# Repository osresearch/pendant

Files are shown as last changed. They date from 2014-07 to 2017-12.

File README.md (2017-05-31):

Bootloader
===

The ATtiny85 needs to be flashed with a bootloader before it can
be programmed with the Arduino IDE.  This requires extra hardware,
such as a teensy or arduino configured as an ISP.

The bootloader is then flashed via an SOIC socket.  It is possible to
via a chip clip, but this seems to be somewhat flakey due to the
charlieplexing matrix.

Using the arduino IDE, select "`File`-`Examples`-`11. Arduino ISP`"
and set the "`Tools`-`Board`" for whatever type of arduino or teensy you 
are using.  For a teensy the minimum pinout is:

	Teensy	SOIC	Use
	Vcc	8
	GND	4
	1	7	SCK
	2	5	MOSI
	3	6	MISO
	10	1	Reset

Clone the bootloader tree:

    git clone https://github.com/osresearch/gemma-bootloader

You might have to edit the `gemma-bootloader/Makefile` to have the
right path to your Arduino build environment and `avrdude` tool.  You will
likely have to edit it to set the serial device that your Teensy or
Arduino shows up as.

Connect the ArduinoISP to the ATtiny85 and flash the bootloader:

    make -C gemma-bootloader flash_lv

This should result in an ok message.  if it doesn't, check the connections
and try again.  If it is succesful you won't be able to reflash it,
since the reset pin is disabled.

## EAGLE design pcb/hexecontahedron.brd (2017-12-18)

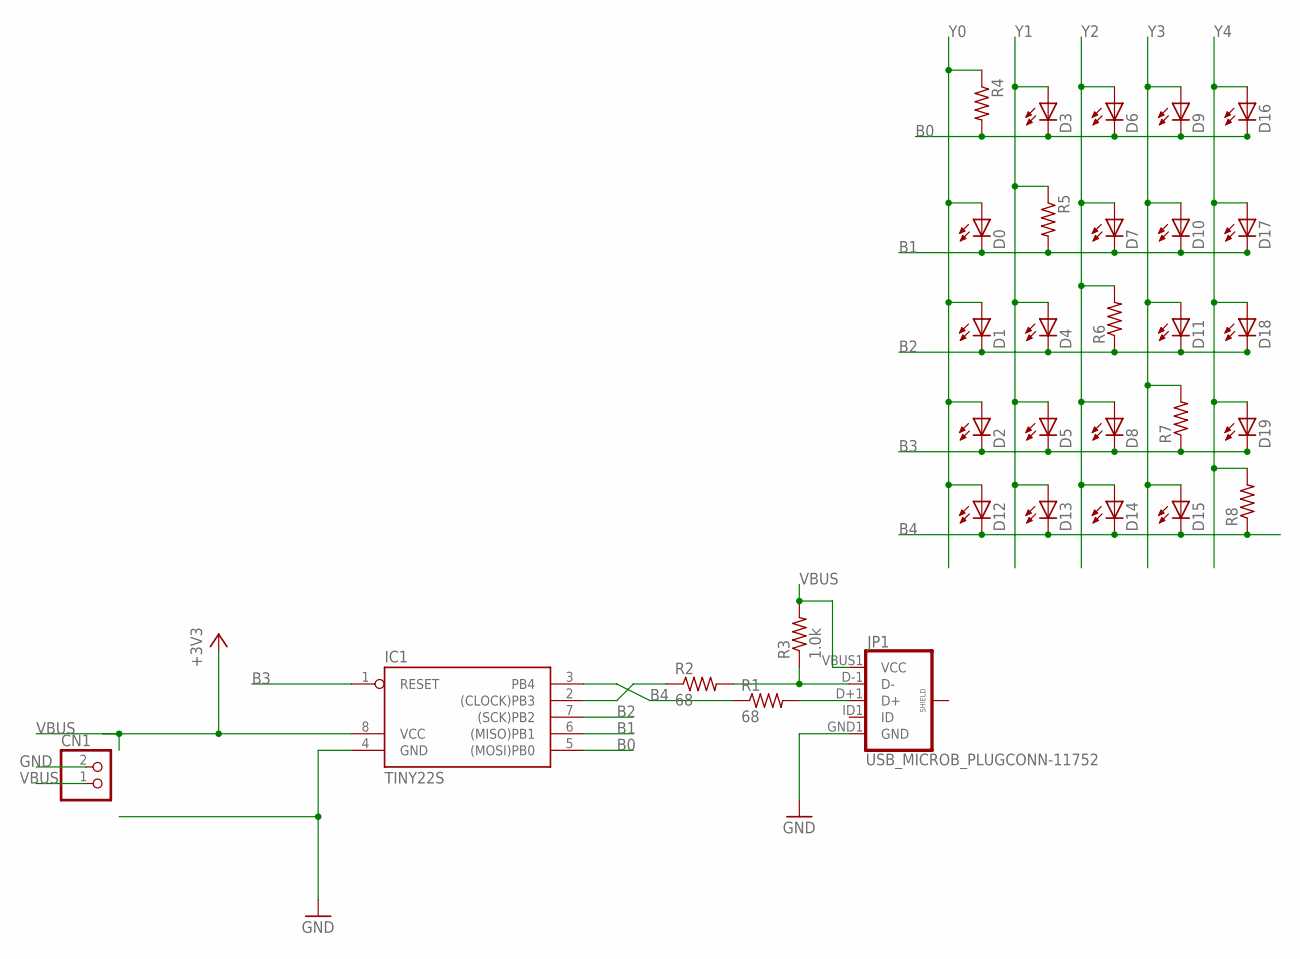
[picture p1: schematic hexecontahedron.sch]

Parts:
CN1: JST_2PIN-THM-RA; JST-PH-2-THM-RA
D0, D1, D2, D3, D4, D5, D6, D7, D8, D9, D10, D11, D12, D13, D14, D15, D16, D17, D18, D19: LEDCHIPLED_0805; CHIPLED_0805
IC1: TINY22S; SOIC8
JP1: USB_MICROB_PLUGCONN-11752; USB-B-MICRO-SMD_V03
R1, R2: 68; R0603
R3: 1.0k; R0603
R4, R5, R6, R7, R8: R-US_R0603; R0603

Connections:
B0: D3.C, D6.C, D9.C, D16.C, IC1.5 ((MOSI)PB0), R4.2
B1: D0.C, D7.C, D10.C, D17.C, IC1.6 ((MISO)PB1), R5.2
B2: D1.C, D4.C, D11.C, D18.C, IC1.7 ((SCK)PB2), R6.1
B3: D2.C, D5.C, D8.C, D19.C, IC1.1 (RESET), R7.1
B4: D12.C, D13.C, D14.C, D15.C, IC1.3 (PB4), R1.1, R8.1
GND: CN1.2 (1), IC1.4 (GND), JP1.GND1 (GND)
unnamed: JP1.D+1 (D+), R1.2
unnamed: JP1.D-1 (D-), R2.2, R3.1
unnamed: IC1.2 ((CLOCK)PB3), R2.1
VBUS: CN1.1 (2), IC1.8 (VCC), JP1.VBUS1 (VCC), R3.2
Y0: D0.A, D1.A, D2.A, D12.A, R4.1
Y1: D3.A, D4.A, D5.A, D13.A, R5.1
Y2: D6.A, D7.A, D8.A, D14.A, R6.2
Y3: D9.A, D10.A, D11.A, D15.A, R7.2
Y4: D16.A, D17.A, D18.A, D19.A, R8.2

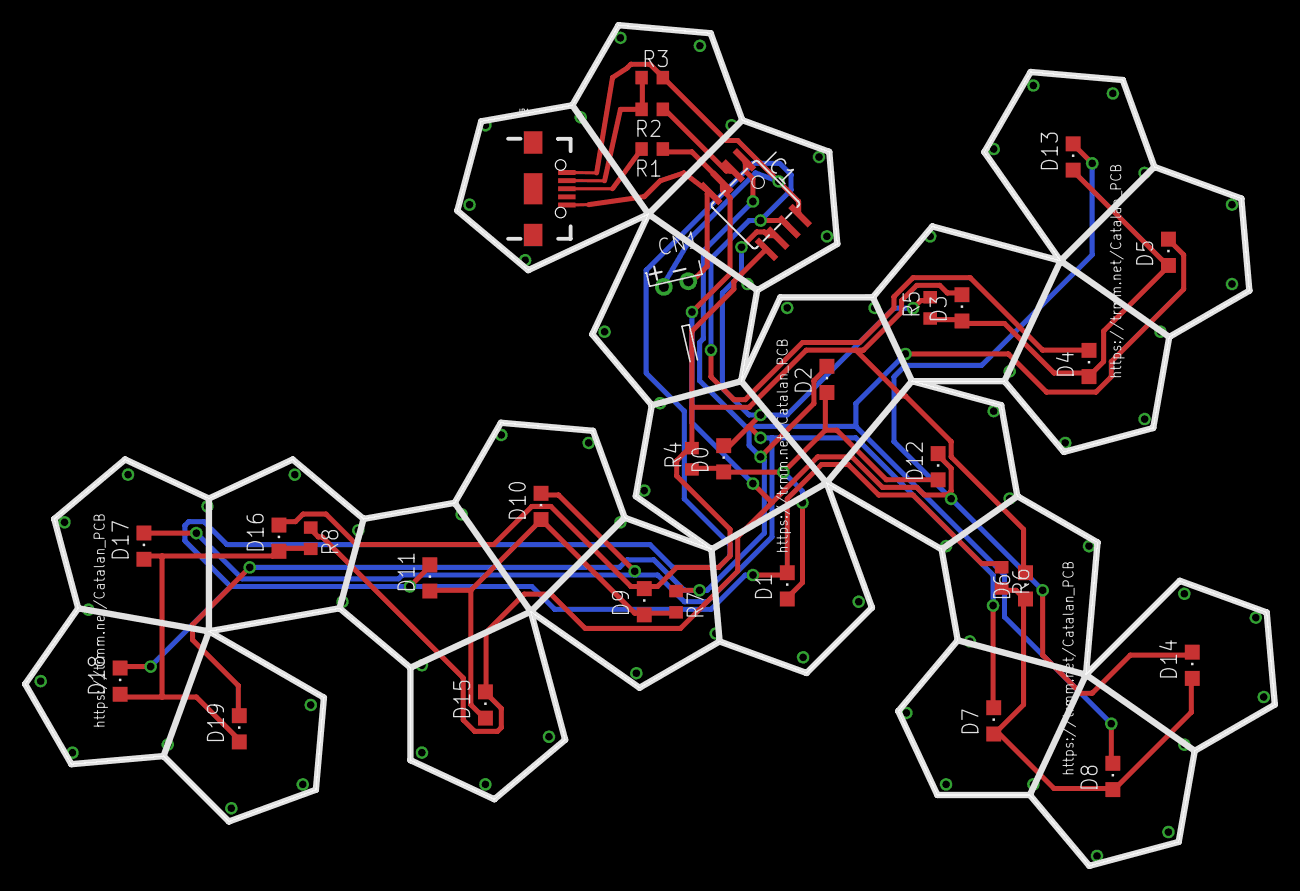
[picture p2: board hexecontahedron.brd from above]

Board: 2 copper layers, 99.9 x 67.2 mm, 31 parts (0 on the bottom side), 15 nets.

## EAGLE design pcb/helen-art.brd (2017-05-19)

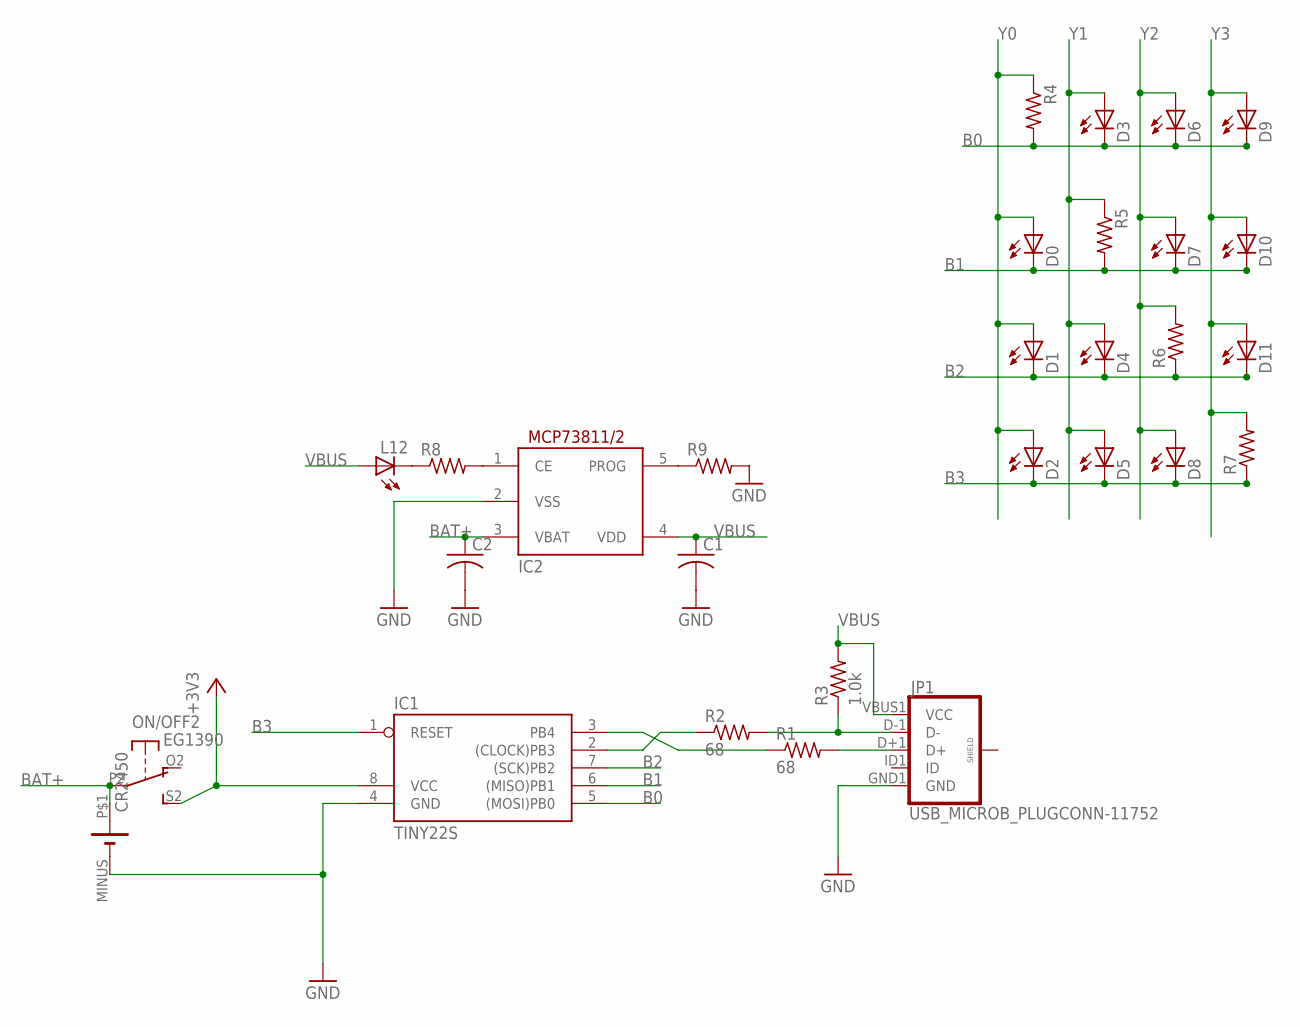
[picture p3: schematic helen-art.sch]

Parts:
C1, C2: C-USC0603; C0603
D0, D1, D2, D3, D4, D5, D6, D7, D8, D9, D10, D11: LEDCHIPLED_0805; CHIPLED_0805
IC1: TINY22S; SOIC8
IC2: MCP73811/2; SOT23-5L
JP1: USB_MICROB_PLUGCONN-11752; USB-B-MICRO-SMD_V03
L12: LEDCHIPLED_0805; CHIPLED_0805
ON/OFF: EG1390
R1, R2: 68; R0603
R3: 1.0k; R0603
R4, R5, R6, R7, R8, R9: R-US_R0603; R0603
U$3: CR2450; CR2450_KEYSTONE

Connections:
+3V3: IC1.8 (VCC), ON/OFF.S2 (S)
B0: D3.C, D6.C, D9.C, IC1.5 ((MOSI)PB0), R4.2
B1: D0.C, D7.C, D10.C, IC1.6 ((MISO)PB1), R5.2
B2: D1.C, D4.C, D11.C, IC1.7 ((SCK)PB2), R6.1
B3: D2.C, D5.C, D8.C, IC1.1 (RESET), R7.1
BAT+: C2.1, IC2.3 (VBAT), ON/OFF.P2, U$3.P$1 (+)
GND: C1.2, C2.2, IC1.4 (GND), IC2.2 (VSS), JP1.GND1 (GND), R9.2, U$3.MINUS (-)
unnamed: JP1.D+1 (D+), R1.2
unnamed: JP1.D-1 (D-), R2.2, R3.1
unnamed: IC1.3 (PB4), R1.1
unnamed: IC1.2 ((CLOCK)PB3), R2.1
unnamed: IC2.5 (PROG), R9.1
unnamed: IC2.1 (CE), R8.2
unnamed: L12.C, R8.1
VBUS: C1.1, IC2.4 (VDD), JP1.VBUS1 (VCC), L12.A, R3.2
Y0: D0.A, D1.A, D2.A, R4.1
Y1: D3.A, D4.A, D5.A, R5.1
Y2: D6.A, D7.A, D8.A, R6.2
Y3: D9.A, D10.A, D11.A, R7.2

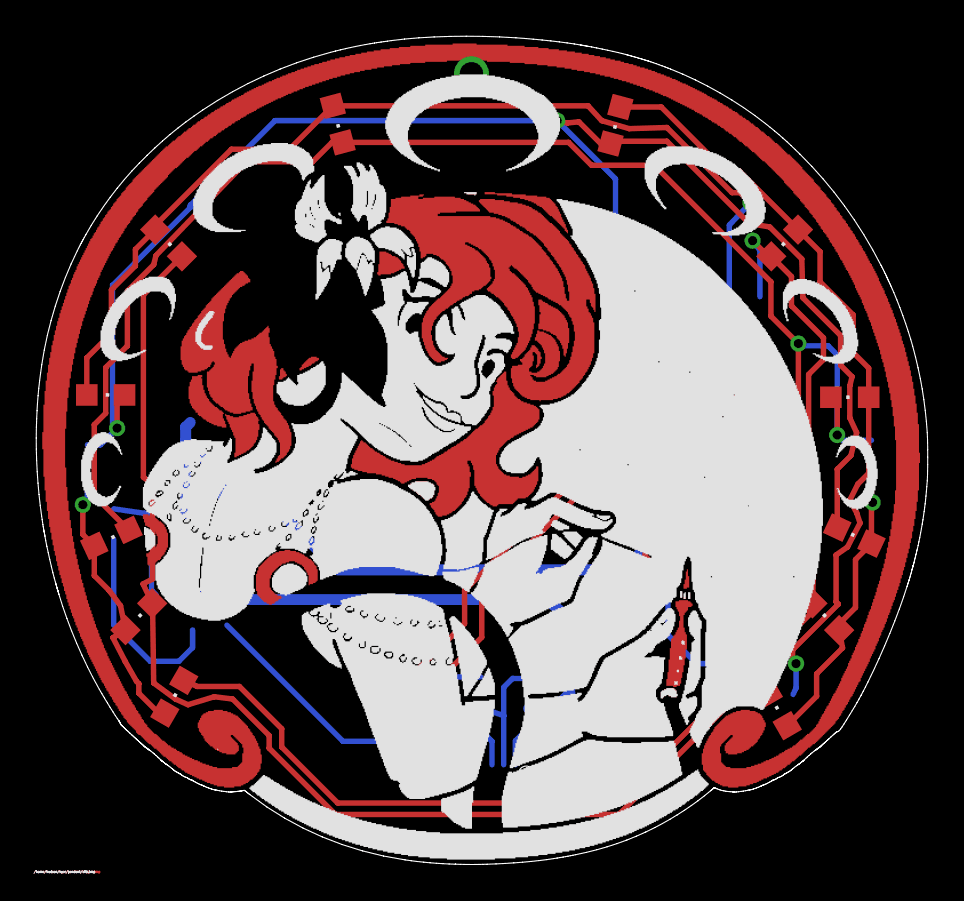
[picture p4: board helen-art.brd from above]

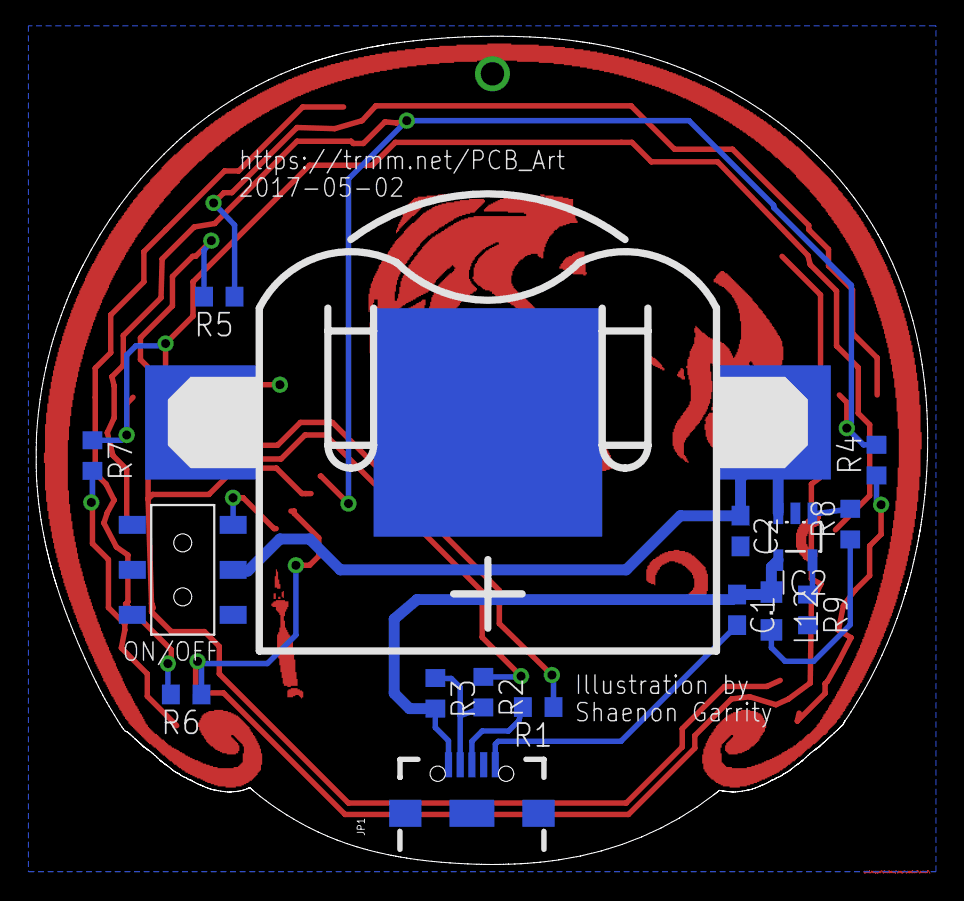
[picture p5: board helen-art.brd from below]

Board: 2 copper layers, 49.5 x 46.0 mm, 29 parts (16 on the bottom side), 19 nets.

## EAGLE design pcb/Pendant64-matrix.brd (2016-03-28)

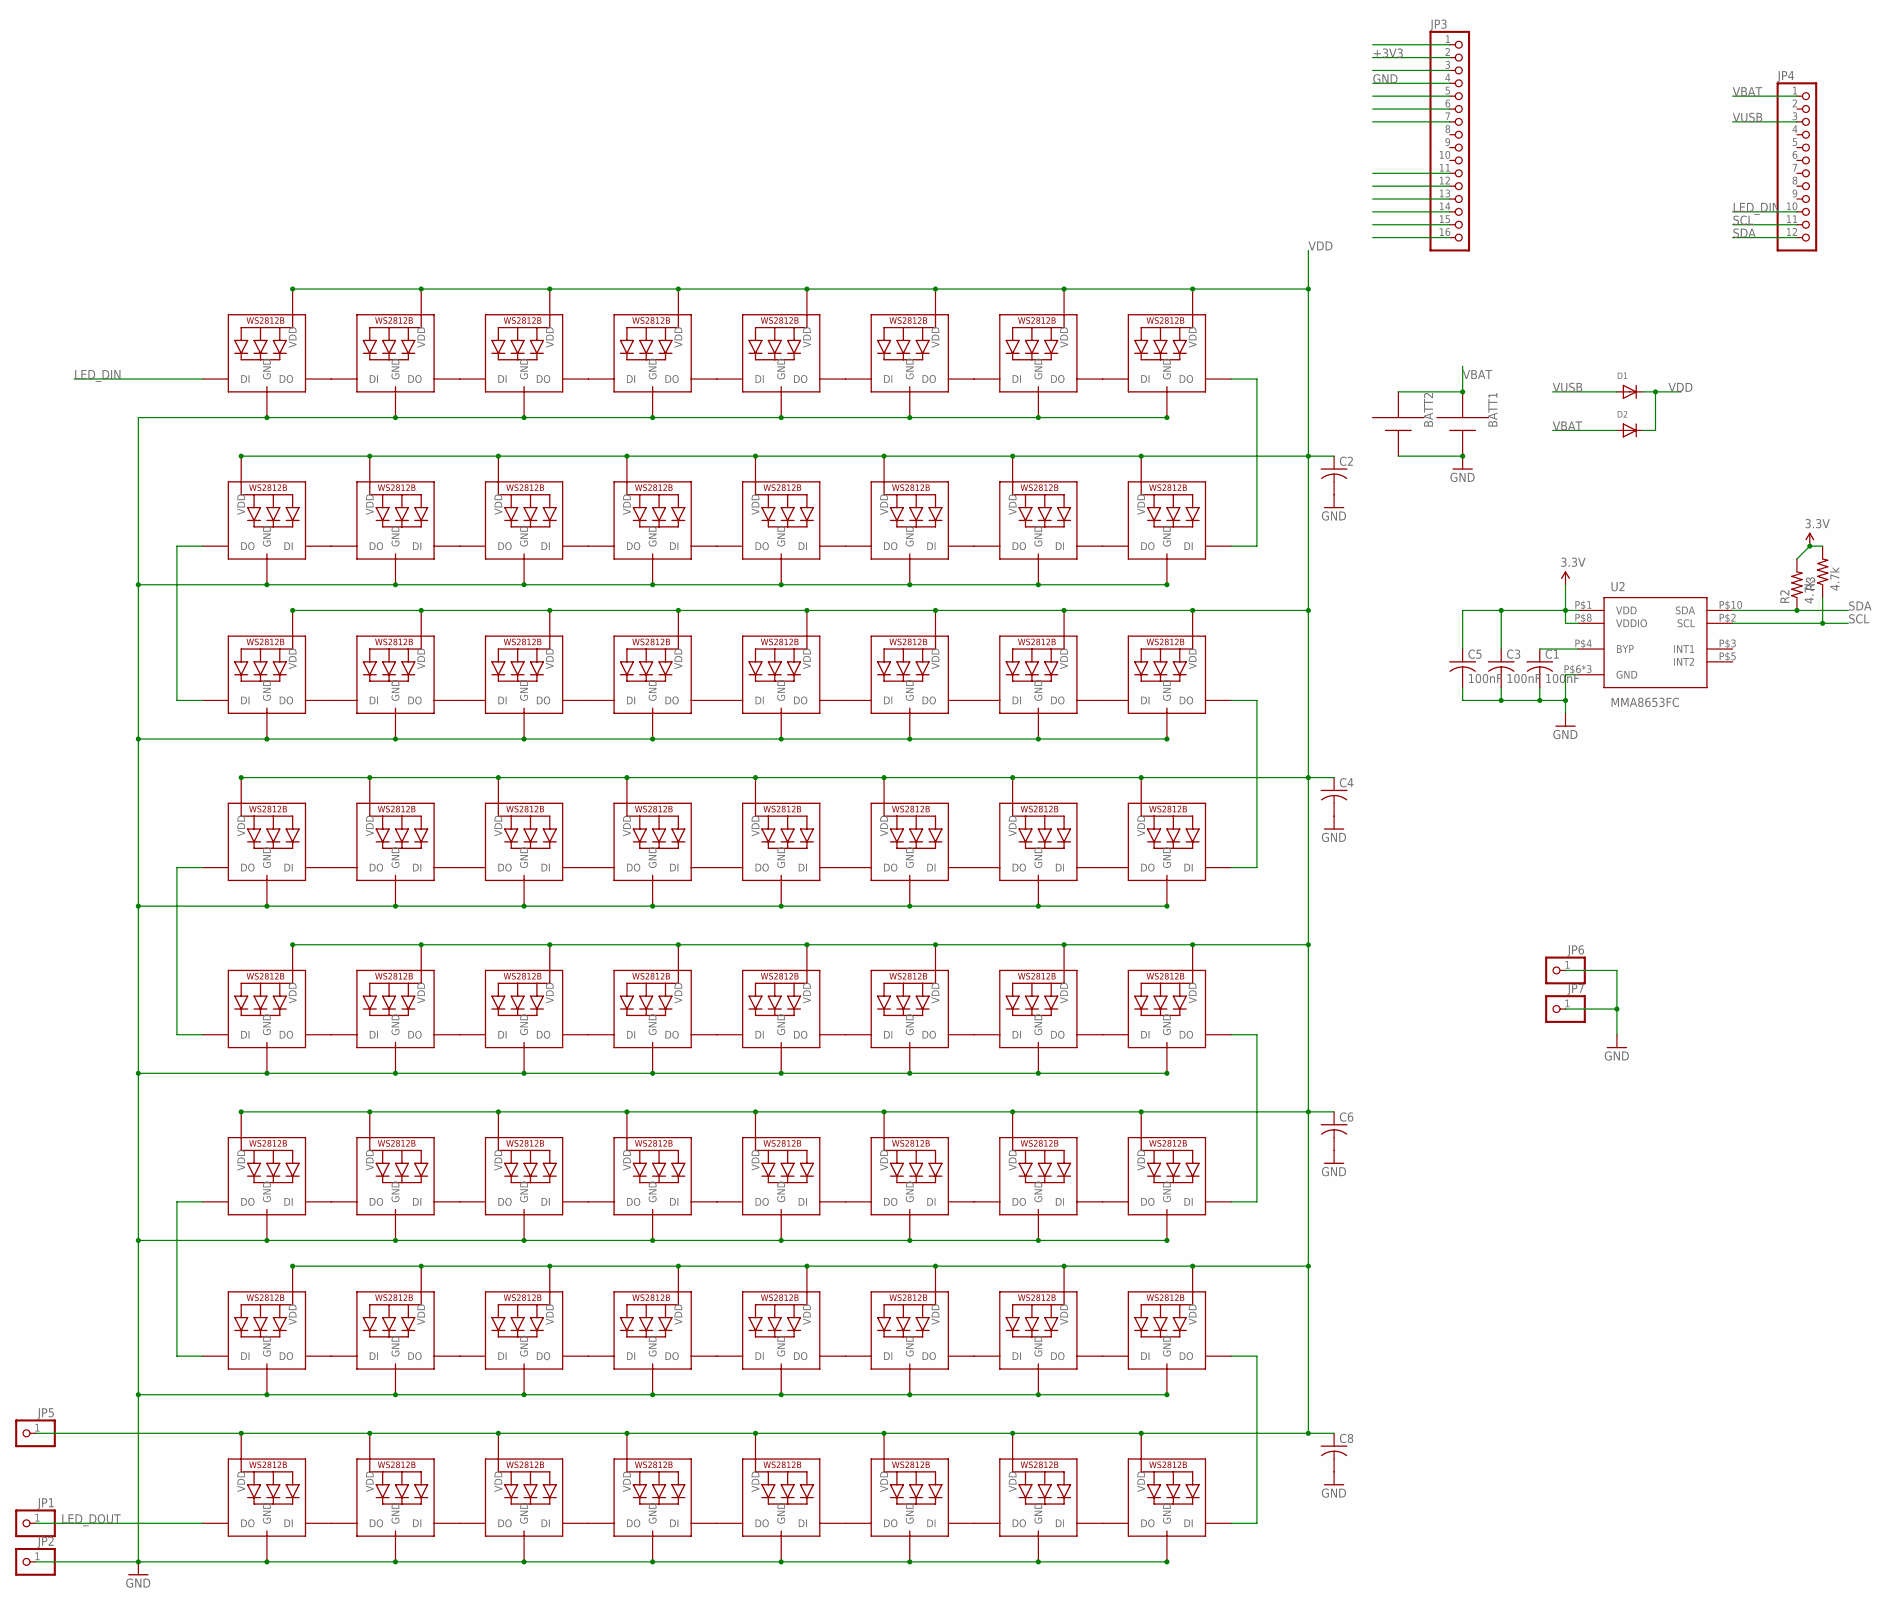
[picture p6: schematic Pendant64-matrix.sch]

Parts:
BATT1, BATT2: AAA; 12BH412
C1, C3, C5: 100nF; C0402
C2, C4, C6, C8: C-USC0402K; C0402K
D1, D2: DIODESOD-123; SOD-123
JP1, JP2, JP5, JP6, JP7: PINHD-1X1; 1X01
JP3: PINHD-1X161X16_SMT; 1X16_SMT
JP4: PINHD-1X121X12_SMT; 1X12_SMT
LED1, LED2, LED3, LED4, LED5, LED6, LED7, LED8, LED9, LED10, LED11, LED12, LED13, LED14, LED15, LED16, LED17, LED18, LED19, LED20, LED21, LED22, LED23, LED24, LED25, LED26, LED27, LED28, LED29, LED30, LED31, LED32, LED33, LED34, LED35, LED36, LED37, LED38, LED39, LED40, LED41, LED42, LED43, LED44, LED45, LED46, LED47, LED48, LED49, LED50, LED51, LED52, LED53, LED54, LED55, LED56, LED57, LED58, LED59, LED60, LED61, LED62, LED63, LED64: WS2812B3535; LED3535
R2, R3: 4.7k; R0402
U2: MMA8653FC; VFDFN-10

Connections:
+3V3: C3.1, C5.1, JP3.2, R2.2, R3.2, U2.P$1 (VDD), U2.P$8 (VDDIO)
GND: BATT1.+, BATT2.+, C1.2, C2.2, C3.2, C4.2, C5.2, C6.2, C8.2, JP2.1, JP3.4, JP6.1, JP7.1, LED1.4 (GND), LED2.4 (GND), LED3.4 (GND), LED4.4 (GND), LED5.4 (GND), LED6.4 (GND), LED7.4 (GND), LED8.4 (GND), LED9.4 (GND), LED10.4 (GND), LED11.4 (GND), LED12.4 (GND), LED13.4 (GND), LED14.4 (GND), LED15.4 (GND), LED16.4 (GND), LED17.4 (GND), LED18.4 (GND), LED19.4 (GND), LED20.4 (GND), LED21.4 (GND), LED22.4 (GND), LED23.4 (GND), LED24.4 (GND), LED25.4 (GND), LED26.4 (GND), LED27.4 (GND), LED28.4 (GND), LED29.4 (GND), LED30.4 (GND), LED31.4 (GND), LED32.4 (GND), LED33.4 (GND), LED34.4 (GND), LED35.4 (GND), LED36.4 (GND), LED37.4 (GND), LED38.4 (GND), LED39.4 (GND), LED40.4 (GND), LED41.4 (GND), LED42.4 (GND), LED43.4 (GND), LED44.4 (GND), LED45.4 (GND), LED46.4 (GND), LED47.4 (GND), LED48.4 (GND), LED49.4 (GND), LED50.4 (GND), LED51.4 (GND), LED52.4 (GND), LED53.4 (GND), LED54.4 (GND), LED55.4 (GND), LED56.4 (GND), LED57.4 (GND), LED58.4 (GND), LED59.4 (GND), LED60.4 (GND), LED61.4 (GND), LED62.4 (GND), LED63.4 (GND), LED64.4 (GND), U2.P$6 (GND), U2.P$7 (GND), U2.P$9 (GND)
LED_DIN: JP4.10, LED1.1 (DI)
LED_DOUT: JP1.1, LED64.3 (DO)
unnamed: LED1.3 (DO), LED2.1 (DI)
unnamed: LED2.3 (DO), LED3.1 (DI)
unnamed: LED3.3 (DO), LED4.1 (DI)
unnamed: LED4.3 (DO), LED5.1 (DI)
unnamed: LED5.3 (DO), LED6.1 (DI)
unnamed: LED6.3 (DO), LED7.1 (DI)
unnamed: LED7.3 (DO), LED8.1 (DI)
unnamed: LED9.3 (DO), LED10.1 (DI)
unnamed: LED10.3 (DO), LED11.1 (DI)
unnamed: LED11.3 (DO), LED12.1 (DI)
unnamed: LED12.3 (DO), LED13.1 (DI)
unnamed: LED13.3 (DO), LED14.1 (DI)
unnamed: LED14.3 (DO), LED15.1 (DI)
unnamed: LED15.3 (DO), LED16.1 (DI)
unnamed: LED17.3 (DO), LED18.1 (DI)
unnamed: LED18.3 (DO), LED19.1 (DI)
unnamed: LED19.3 (DO), LED20.1 (DI)
unnamed: LED20.3 (DO), LED21.1 (DI)
unnamed: LED21.3 (DO), LED22.1 (DI)
unnamed: LED22.3 (DO), LED23.1 (DI)
unnamed: LED23.3 (DO), LED24.1 (DI)
unnamed: LED25.3 (DO), LED26.1 (DI)
unnamed: LED26.3 (DO), LED27.1 (DI)
unnamed: LED27.3 (DO), LED28.1 (DI)
unnamed: LED28.3 (DO), LED29.1 (DI)
unnamed: LED29.3 (DO), LED30.1 (DI)
unnamed: LED30.3 (DO), LED31.1 (DI)
unnamed: LED31.3 (DO), LED32.1 (DI)
unnamed: LED33.3 (DO), LED34.1 (DI)
unnamed: LED34.3 (DO), LED35.1 (DI)
unnamed: LED8.3 (DO), LED9.1 (DI)
unnamed: LED16.3 (DO), LED17.1 (DI)
unnamed: LED24.3 (DO), LED25.1 (DI)
unnamed: LED32.3 (DO), LED33.1 (DI)
unnamed: LED35.3 (DO), LED36.1 (DI)
unnamed: LED36.3 (DO), LED37.1 (DI)
unnamed: LED37.3 (DO), LED38.1 (DI)
unnamed: LED38.3 (DO), LED39.1 (DI)
unnamed: LED39.3 (DO), LED40.1 (DI)
unnamed: LED41.3 (DO), LED42.1 (DI)
unnamed: LED42.3 (DO), LED43.1 (DI)
unnamed: LED43.3 (DO), LED44.1 (DI)
unnamed: LED44.3 (DO), LED45.1 (DI)
unnamed: LED45.3 (DO), LED46.1 (DI)
unnamed: LED46.3 (DO), LED47.1 (DI)
unnamed: LED47.3 (DO), LED48.1 (DI)
unnamed: LED49.3 (DO), LED50.1 (DI)
unnamed: LED50.3 (DO), LED51.1 (DI)
unnamed: LED51.3 (DO), LED52.1 (DI)
unnamed: LED52.3 (DO), LED53.1 (DI)
unnamed: LED53.3 (DO), LED54.1 (DI)
unnamed: LED54.3 (DO), LED55.1 (DI)
unnamed: LED55.3 (DO), LED56.1 (DI)
unnamed: LED57.3 (DO), LED58.1 (DI)
unnamed: LED58.3 (DO), LED59.1 (DI)
unnamed: LED59.3 (DO), LED60.1 (DI)
unnamed: LED60.3 (DO), LED61.1 (DI)
unnamed: LED61.3 (DO), LED62.1 (DI)
unnamed: LED62.3 (DO), LED63.1 (DI)
unnamed: LED63.3 (DO), LED64.1 (DI)
unnamed: C1.1, U2.P$4 (BYP)
unnamed: LED40.3 (DO), LED41.1 (DI)
unnamed: LED48.3 (DO), LED49.1 (DI)
unnamed: LED56.3 (DO), LED57.1 (DI)
SCL: JP4.11, R3.1, U2.P$2 (SCL)
SDA: JP4.12, R2.1, U2.P$10 (SDA)
VBAT: BATT1.-, BATT2.-, D2.A, JP4.1
VDD: C2.1, C4.1, C6.1, C8.1, D1.C, D2.C, JP5.1, LED1.2 (VDD), LED2.2 (VDD), LED3.2 (VDD), LED4.2 (VDD), LED5.2 (VDD), LED6.2 (VDD), LED7.2 (VDD), LED8.2 (VDD), LED9.2 (VDD), LED10.2 (VDD), LED11.2 (VDD), LED12.2 (VDD), LED13.2 (VDD), LED14.2 (VDD), LED15.2 (VDD), LED16.2 (VDD), LED17.2 (VDD), LED18.2 (VDD), LED19.2 (VDD), LED20.2 (VDD), LED21.2 (VDD), LED22.2 (VDD), LED23.2 (VDD), LED24.2 (VDD), LED25.2 (VDD), LED26.2 (VDD), LED27.2 (VDD), LED28.2 (VDD), LED29.2 (VDD), LED30.2 (VDD), LED31.2 (VDD), LED32.2 (VDD), LED33.2 (VDD), LED34.2 (VDD), LED35.2 (VDD), LED36.2 (VDD), LED37.2 (VDD), LED38.2 (VDD), LED39.2 (VDD), LED40.2 (VDD), LED41.2 (VDD), LED42.2 (VDD), LED43.2 (VDD), LED44.2 (VDD), LED45.2 (VDD), LED46.2 (VDD), LED47.2 (VDD), LED48.2 (VDD), LED49.2 (VDD), LED50.2 (VDD), LED51.2 (VDD), LED52.2 (VDD), LED53.2 (VDD), LED54.2 (VDD), LED55.2 (VDD), LED56.2 (VDD), LED57.2 (VDD), LED58.2 (VDD), LED59.2 (VDD), LED60.2 (VDD), LED61.2 (VDD), LED62.2 (VDD), LED63.2 (VDD), LED64.2 (VDD)
VUSB: D1.A, JP4.3

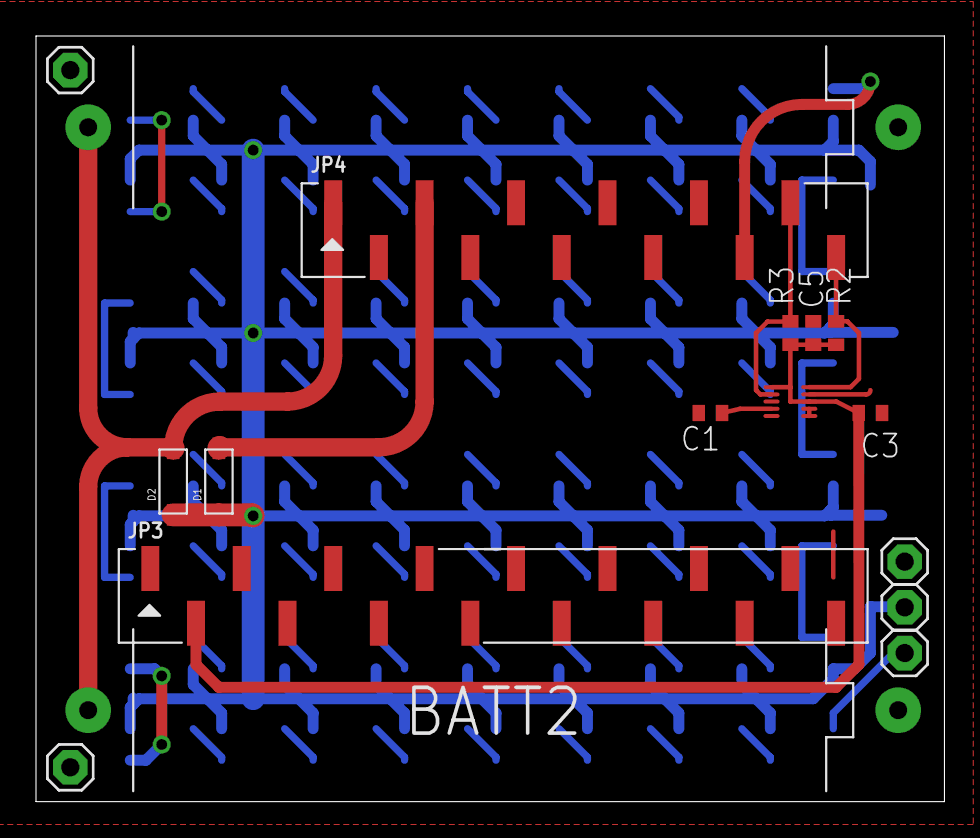
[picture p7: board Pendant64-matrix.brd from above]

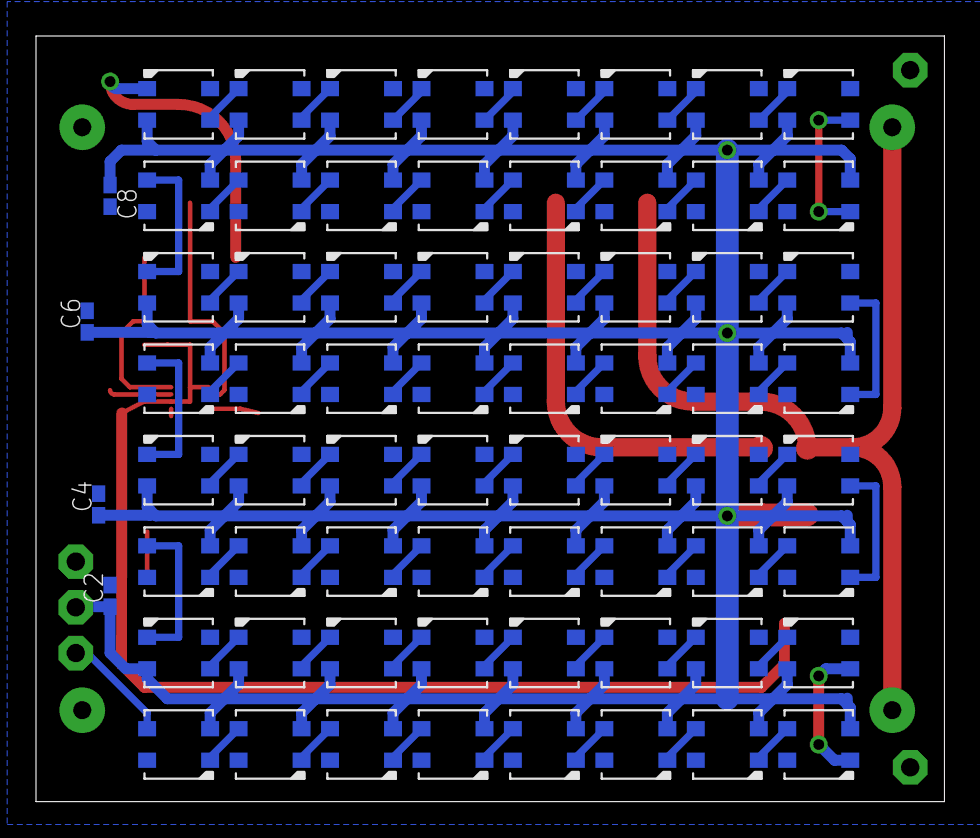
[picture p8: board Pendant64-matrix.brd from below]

Board: 2 copper layers, 50.5 x 42.5 mm, 85 parts (68 on the bottom side), 73 nets.

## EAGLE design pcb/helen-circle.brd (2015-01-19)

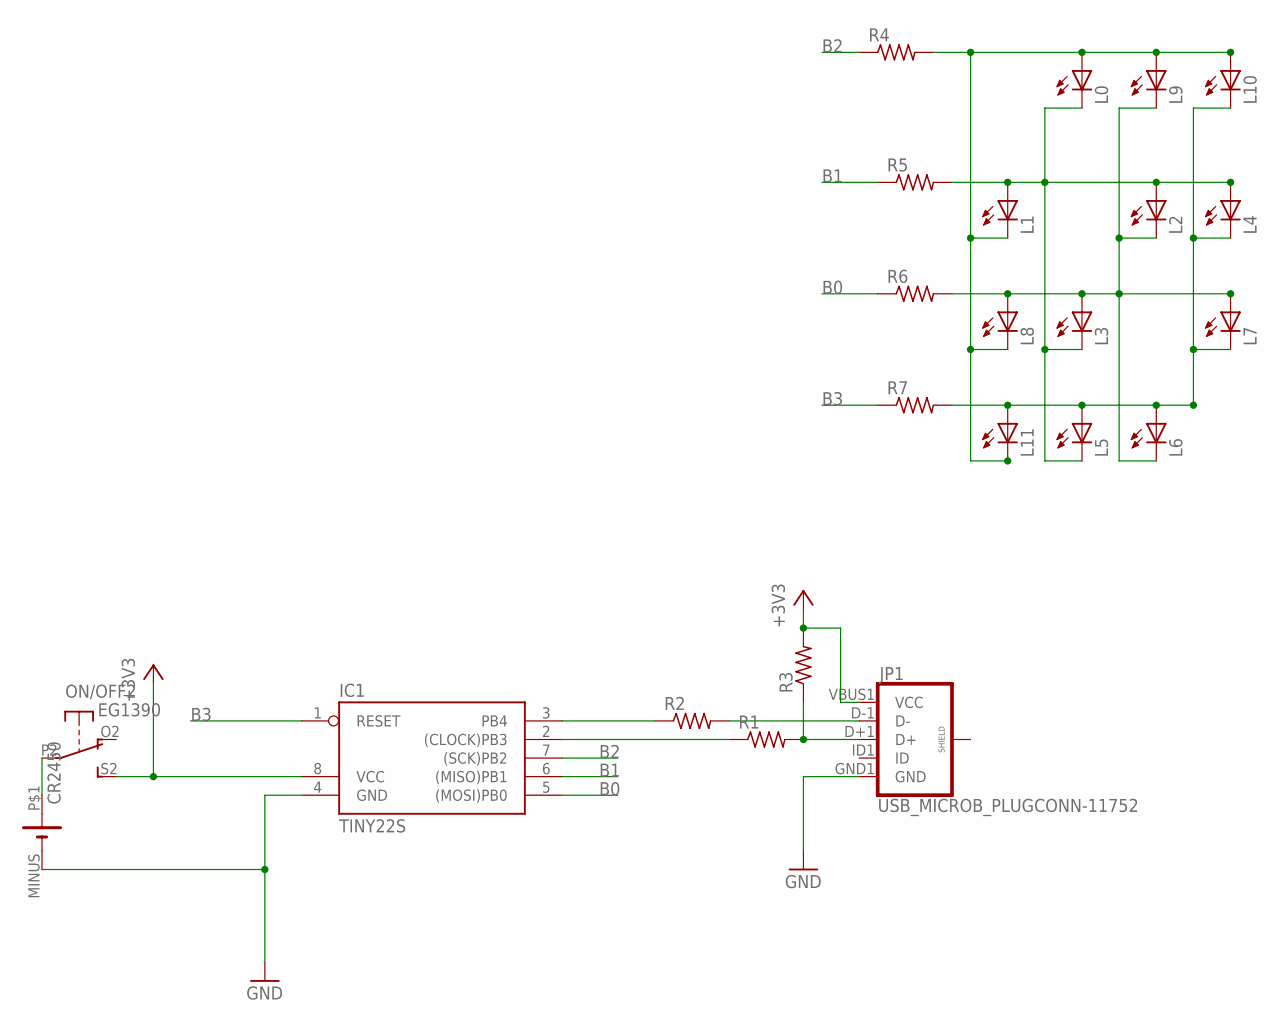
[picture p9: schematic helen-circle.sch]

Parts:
IC1: TINY22S; SOIC8
JP1: USB_MICROB_PLUGCONN-11752; USB-B-MICRO-SMD_V03
L0, L1, L2, L3, L4, L5, L6, L7, L8, L9, L10, L11: LEDCHIPLED_0805; CHIPLED_0805
ON/OFF: EG1390
R1, R2, R3, R4, R5, R6, R7: R-US_R0603; R0603
U$3: CR2450; CR2450_KEYSTONE

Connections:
+3V3: IC1.8 (VCC), JP1.VBUS1 (VCC), ON/OFF.S2 (S), R3.2
B0: IC1.5 ((MOSI)PB0), R6.1
B0': L2.C, L3.A, L6.C, L7.A, L8.A, L9.C, R6.2
B1: IC1.6 ((MISO)PB1), R5.1
B1': L0.C, L1.A, L2.A, L3.C, L4.A, L5.C, R5.2
B2: IC1.7 ((SCK)PB2), R4.1
B2': L0.A, L1.C, L8.C, L9.A, L10.A, L11.C, R4.2
B3: IC1.1 (RESET), R7.1
B3': L4.C, L5.A, L6.A, L7.C, L10.C, L11.A, R7.2
GND: IC1.4 (GND), JP1.GND1 (GND), U$3.MINUS (-)
unnamed: JP1.D+1 (D+), R1.2, R3.1
unnamed: JP1.D-1 (D-), R2.2
unnamed: IC1.2 ((CLOCK)PB3), R1.1
unnamed: IC1.3 (PB4), R2.1
unnamed: ON/OFF.P2, U$3.P$1 (+)

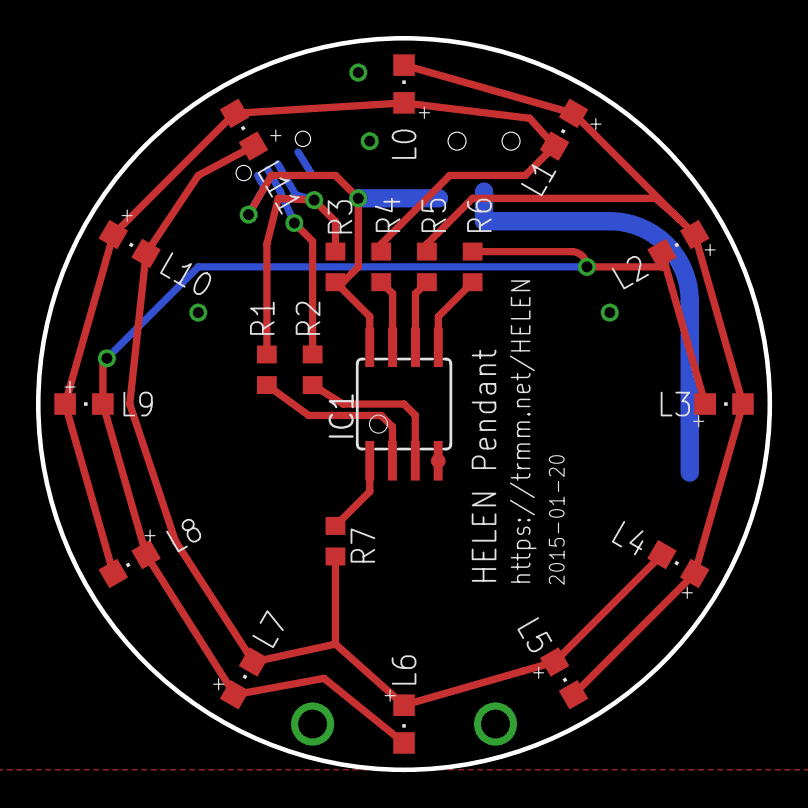
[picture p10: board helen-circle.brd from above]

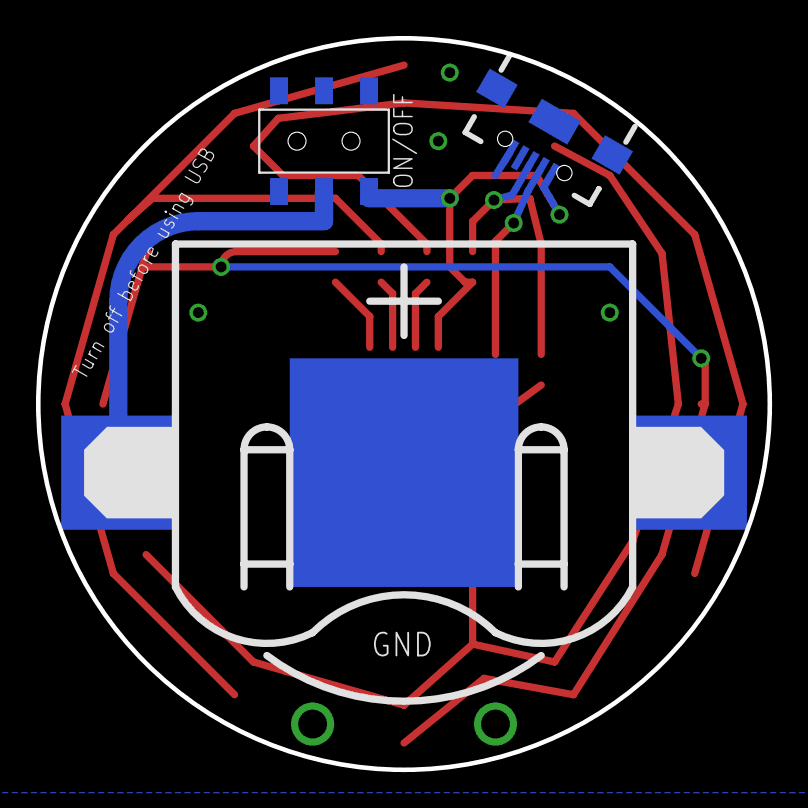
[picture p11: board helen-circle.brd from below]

Board: 2 copper layers, 40.6 x 40.6 mm, 23 parts (3 on the bottom side), 15 nets.

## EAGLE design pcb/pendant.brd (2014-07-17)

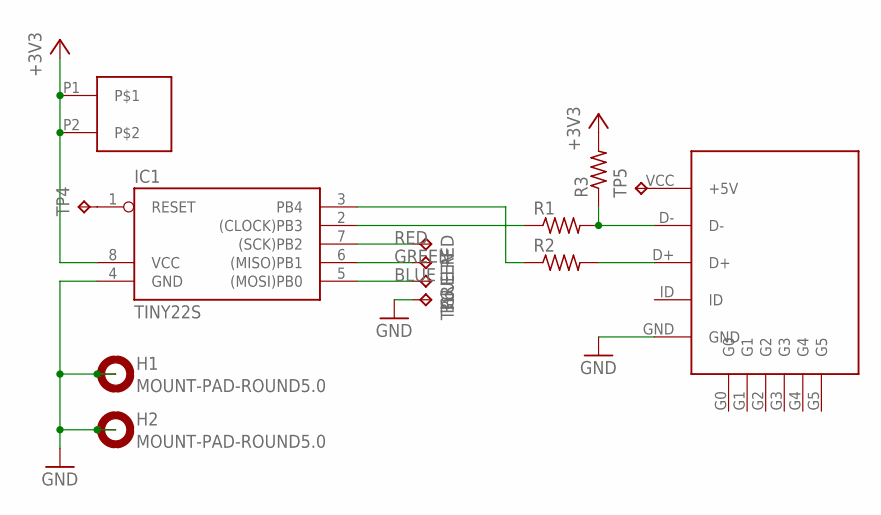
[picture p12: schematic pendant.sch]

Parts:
BLUE: TPPAD1-13; P1-13
GREEN: TPPAD1-13; P1-13
H1, H2: MOUNT-PAD-ROUND5.0; 5,0-PAD
IC1: TINY22S; SOIC8
R1, R2, R3: R-US_R0603; R0603
RED: TPPAD1-13; P1-13
TP4, TP6: TPPAD1-13; P1-13
TP5: TPTP10SQ; TP10SQ
U$1: USB-MICRO; UB-MC5BR3-M404
U$2: MAGNET8TH-INCH; 8TH-SQUARE

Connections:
+3V3: IC1.8 (VCC), R3.2, U$2.P1, U$2.P2
BLUE: BLUE.TP, IC1.5 ((MOSI)PB0)
G0: U$1.G0
G1: U$1.G1
G2: U$1.G2
G3: U$1.G3
G4: U$1.G4
G5: U$1.G5
GND: H1.B5, H2.B5, IC1.4 (GND), TP6.TP, U$1.GND
GREEN: GREEN.TP, IC1.6 ((MISO)PB1)
unnamed: R1.2, R3.1, U$1.D-
unnamed: R2.2, U$1.D+
unnamed: IC1.2 ((CLOCK)PB3), R1.1
unnamed: IC1.3 (PB4), R2.1
unnamed: IC1.1 (RESET), TP4.TP
unnamed: TP5.TP, U$1.VCC (+5V)
RED: IC1.7 ((SCK)PB2), RED.TP


Board: 2 copper layers, 24.1 x 24.1 mm, 14 parts (0 on the bottom side), 11 nets.

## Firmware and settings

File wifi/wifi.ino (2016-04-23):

/** \file
 * WiFi LED pendant with games.
 *
 * nc won't send to broadcast UDP addresses.  Instead use socat:
 *
 * socat - UDP4-DATAGRAM:192.168.1.255:9999,broadcast
 *
 * Start in station mode and periodically scan for networks named
 * "leader-XYZ".  If one is available, join it and contact the server.
 * If none is available, wait some period of time and then create one.
 * 
 * WiFi docs: http://www.arduino.cc/en/Reference/WiFi
 */

#include <ESP8266WiFi.h>
#include <WiFiUdp.h>
#include <Adafruit_NeoPixel.h>
//#include <Adafruit_ADXL345_U.h>
#include "color.h"

// LED matrix display
#define WIDTH 8
#define HEIGHT 4
#define NUM_PIXELS (WIDTH * HEIGHT)
#define LED_PIN 15

Adafruit_NeoPixel leds = Adafruit_NeoPixel(WIDTH*HEIGHT, LED_PIN, NEO_GRB);
float t = 0;
int status_led;

int mode;

float fb[WIDTH][HEIGHT][3];

// i2c connected accelerometer
//Adafruit_ADXL345_Unified accel = Adafruit_ADXL345_Unified(12345);

// Network config
#define UDP_PORT 9999
WiFiUDP udp;

#define MODE_SCANNING 0
#define MODE_FOLLOWER 1
#define MODE_CANDIDATE 2
#define MODE_LEADER 3

int wifi_my_id;
uint32_t my_color;
int wifi_mode = 0; // scanning, joined, leader

uint32_t last_draw_time; // when LEDs were last displayed

// Possible colors that leader can assign to followers
uint32_t assignment_colors[] = {
	leds.Color(255, 20, 0),
	leds.Color(255, 100, 0),
	leds.Color(255, 255, 30),
	leds.Color(0, 255, 30),
	leds.Color(0, 255, 150),
	leds.Color(0, 30, 255),
	leds.Color(255, 20, 80),
};
#define COLORS_LENGTH 7
uint32_t used_colors[COLORS_LENGTH];

#define SCAN_INTERVAL 5000
int last_scan = 0; // periodic scanning timer, ms of last scan
int wifi_scans = 0; // how many scans have we done?

#define BEACON_INTERVAL 1000
int last_beacon;


// leaders will start their network names with this prefix
String wifi_prefix = "blinky-";


// Network packet for beacons
#define BEACON_MAGIC 0xdecafbad
// Network packet for assignments
#define ASSIGN_MAGIC 0xcafefade

// The message type, for broadcast beacons and assignment messages
typedef struct
{
	uint32_t magic; // distiguishes beacons from assignments
	uint32_t id;
	uint32_t color; // self color in beacons, assigned color in assignments
} message_t;


typedef struct
{
	uint32_t leader_id;
	uint32_t leader_color;
	int leader_beacon_ms;	
	int my_beacon_ms;
} follower_state_t;

follower_state_t follower_state;

typedef struct
{
	uint32_t follower_id;
	uint32_t follower_color;
	int follower_beacon_ms;	
} followling_state_t;

#define MAX_FOLLOWLINGS 16
followling_state_t followlings[MAX_FOLLOWLINGS];

void setup()
{
	WiFi.persistent(false);
	WiFi.mode(WIFI_STA);
	//WiFi.begin(ssid, password);

	udp.begin(UDP_PORT);
	last_scan = millis();

	// generate a random id for ourselves, and initialize our color to white
	wifi_my_id = random(99998) + 1;
	my_color = leds.Color(255, 20, 0);
	//my_color = Wheel(random(256));

	leds.begin();
	leds.setBrightness(32);

	//rc = accel.begin();


	// setup the serial port and also let the RTOS print
	// debugging information to the serial port
	Serial.begin(115200);
	if(0) Serial.setDebugOutput(true);
}

uint8_t buf[128];
const float smooth = 0;
float ax, ay, az;

/*
 * Empty array when full
 */
void empty_used_if_full()
{
	for (int i = 0; i < COLORS_LENGTH; i++)
	{
		int spots_taken = 0;
		if (used_colors[i] != 0)
		{
			spots_taken++;
		}

		// if it's full, empty it:
		if (spots_taken >= COLORS_LENGTH)
		{
			Serial.println("Used colors array is full, setting all to zero");
			for (int i = 0; i < COLORS_LENGTH; i++)
			{
				used_colors[i] = 0;
			}
		}
	}
}

/* 
 * used_colors.push(new_used_color)
 */
void add_to_used(uint32_t color)
{
	for (int i = 0; i < COLORS_LENGTH; i++)
	{
		if (used_colors[i] != 0)
		{
			continue;
		}
		used_colors[i] = color;
		Serial.print("adding new used color. array is now: ");
		for (int i = 0; i < COLORS_LENGTH; i++)
		{
			Serial.println(used_colors[i]);
		}
		return;	
	}
	// TODO - I'm getting this message
	Serial.println("ERROR: The used_colors array was full when it should not be");	
}

// Takes a pointer to a struct that is formed from the
// incoming beacon, and use that to create the new followling entry
// if the followling is not already in the array.
static followling_state_t* find_followling(uint32_t follower_id, IPAddress ip)
{
	// if the followling is already in the array, return a ref to it
	for (int i = 0; i < MAX_FOLLOWLINGS; i++)
	{
		followling_state_t* f = &followlings[i];
		if ( follower_id == f->follower_id ) return f;
	}

	uint32_t now = millis();
	// we have a new followling, find it a slot in the array
	for (int i = 0; i < MAX_FOLLOWLINGS; i++)
	{
		followling_state_t* f = &followlings[i];

		// TODO - suspect this is getting triggered every time
		// If the current followling is still around, skip to next slot
		if (now - f->follower_beacon_ms < 60000) continue;	

		// f is a free space.  Replace the element with the current followling,	
		// and send a color assignment to the follower.
		f->follower_id = follower_id;

		// Pick a color to assign to followling
		f->follower_color = assignment_colors[random(COLORS_LENGTH)];

#if 0
		// Pick a random color and assign it this followlings' state
		int again = 1;
		while(again == 1) {
			uint32_t potential_color = assignment_colors[random(COLORS_LENGTH)];
			empty_used_if_full();
		
			int tried = 0;
			// if used, add to used array and try another
			for (int i = 0; i < COLORS_LENGTH; i++)
			{
				if (potential_color == used_colors[i])
				{
					break;	
				} else {
					tried++;
				}
				if (tried == COLORS_LENGTH)
				{
					// mark it as used
					add_to_used(potential_color);
					// update followling state
					f->follower_color = potential_color;
					again = 0;
				}
			}
		}
#endif

		// now send out that color assignment to the follower
		message_t message = {
			ASSIGN_MAGIC,
			wifi_my_id,
			f->follower_color
		};
		udp.beginPacket(ip, UDP_PORT);
		udp.write((const uint8_t*) &message, sizeof(message));
		udp.endPacket();
		
		Serial.print("Adding follower: ");
		Serial.print(f->follower_id);
		Serial.print(" at index: ");
		Serial.print(i);
		return f;
	}
	
	// No free spaces!!!
	return NULL;
}

/*
 * Parse a follower packet along with an IP if it's the first packet from
 * a follower (so we can assign it back a color and whatever else)
 */
boolean parse_follower_packet(const message_t* message, IPAddress ip)
{
	// Not one of ours.
	if (message->magic != BEACON_MAGIC && message->magic != ASSIGN_MAGIC)
	{
		Serial.println("unable to parse packet");
		return false;
	} 

	if (message->magic == BEACON_MAGIC)
	{
		Serial.println("follower: ");
		Serial.println(message->id);
		
		// First, is this a new followling? 
		followling_state_t* f = find_followling(message->id, ip);
	
		// There was no space to put the new followling
		if (!f)
		{
			//TODO - we're getting this message over and over
			Serial.println("No free space in array for new followling");
			return false;
		}

		// Finish setting the data for the followling
		f->follower_beacon_ms = millis();

		return true;
	}

	if (message->magic == ASSIGN_MAGIC)
	{
			Serial.println("This message was an assignment, not a follower beacon");
			return false;
	}

}

/*
 * Scan the networks, looking for one that matches our prefix.
 *
 * Returns 0 if it is not time to scan again, -1 if there are no leaders,
 * otherwise the id of the lowest leader number seen.
 */
int rescan_network()
{
	const int now = millis();
	if (now - last_scan < SCAN_INTERVAL)
		return 0;
	last_scan = now;

	Serial.print("mode: ");
	Serial.print(wifi_mode);
	Serial.print(" scans: ");
	Serial.println(wifi_scans++);

	int min_leader = -1;
	int num = WiFi.scanNetworks();
	if (num < 0)
	{
		Serial.println("wifi scan failed?");
		return -1;
	}

	for(int i = 0 ; i < num ; i++)
	{
		Serial.print(i);
		Serial.print(' ');
		String ssid = WiFi.SSID(i);
		Serial.print(ssid);
		Serial.print(' ');
		Serial.print(WiFi.RSSI(i));

		// does the SSID match our pattern?
		if (ssid.startsWith(wifi_prefix))
		{
			// extract out the integer at the end
			String idstr = ssid.substring(wifi_prefix.length());
			int leader_id = idstr.toInt();
			Serial.print(" leader ");
			Serial.print(leader_id);
			if (min_leader > leader_id || min_leader == -1)
				min_leader = leader_id;
		}

		Serial.println();
	}

	if (min_leader < 0)
	{
		Serial.println("!!! No leaders found");
	} else {
		Serial.print("Possible leader: ");
		Serial.println(min_leader);
	}

	return min_leader;
}

/*
 * Pixel display patterns for the various modes
 */
// variables used by the color patterns
int brightness = 0;
int direction = 1;
int dim_levels[] = {2, 4, 8, 16, 32, 64, 128};
int position = 0;
uint32_t scan_color = leds.Color(255, 255, 255);
void scanning_pattern() 
{
	if (random(0) == 0) {
		// turn them all off
		for (int i = 0; i < NUM_PIXELS; i++)
			leds.setPixelColor(i, 0, 0, 0);	

		// color the pixels
		if (direction == 1) {
			for (int i = 0; i < 7; i++)
				leds.setPixelColor(position+i, rgb_dim(scan_color, dim_levels[i]));
		} else if (direction == -1) {
			for (int i = 7-1; i > 0; i--) 
				leds.setPixelColor(position-i, rgb_dim(scan_color, dim_levels[i]));
		}
		leds.show();
		
		// change direction as necessary
		if (position == NUM_PIXELS) {
			direction = -1;
		} else if (position == 0) {
			direction = 1;
		}	
		position = position + direction;
		delay(20);	
	}
}

void candidate_pattern()
{
	uint32_t now = millis();

	if (now - last_draw_time < 100) {
		return;
	}

	int brightness = 256 - (millis() - last_beacon) / 4;
	if (brightness < 0)
		brightness = 0;
	int color = rgb_dim(my_color, brightness);

	for (int i = 0; i < NUM_PIXELS; i++) {
		leds.setPixelColor(i, color);
	}
	leds.show();
	last_draw_time = now;
}

void follower_pattern()
{
	uint32_t now = millis();

	if (now - last_draw_time < 30) {
		return;
	}

	uint32_t leader_color = follower_state.leader_color;
	int lead_beacon_age = now - follower_state.leader_beacon_ms;
	int my_beacon_age = now - follower_state.my_beacon_ms;
	
	// If we haven't heard a leader beacon in a while, start scanning
	if (lead_beacon_age > 60000) {
		wifi_mode = MODE_SCANNING;	
	} else {
		leader_color = rgb_dim(leader_color, 256 - (lead_beacon_age/4));	
	}

	// flash my color when I send a beacon
	uint32_t self_color = rgb_dim(my_color, 256 - (my_beacon_age/4));
	for (int i = 0; i < NUM_PIXELS; i++) {
		leds.setPixelColor(i, self_color);
	}

	// include the my leader's color from the beacon
	for(int i = 0 ; i < NUM_PIXELS ; i += 4)
		leds.setPixelColor(i, leader_color);
	leds.show();

	last_draw_time = now;

	// delay so the pixels don't get flickery
	delay(10);
}

void leader_pattern() {
	uint32_t now = millis();

	if (now - last_draw_time < 100) {
		return;
	}

	// solid self color
	int self_color = rgb_dim(my_color, 255);
	leds.setPixelColor(0, self_color);
	leds.setPixelColor(1, self_color);

	// Self color that pulses with beacons sent
	int s_brightness = 256 - (now - last_beacon) / 4;
	int s_color = rgb_dim(my_color, s_brightness);

	int next_led = 2; // skip the first 2 solid self-colored ones

	// followling colors
	for (int i = 0; i < MAX_FOLLOWLINGS; i++) 
	{
		followling_state_t* f = &followlings[i];

		// we have a followling in this space, and it's still around
		if (f->follower_id && (now - f->follower_beacon_ms < 60000)) 
		{
			int f_brightness = 256 - (now - f->follower_beacon_ms) / 4;
			int f_color = rgb_dim(f->follower_color, f_brightness);
			leds.setPixelColor(i+2, f_color); // use followling color
			next_led++;
		} else {
			// this index is empty or has a lost follower
			leds.setPixelColor(i+2, s_color); // use self-color		
		}

	}

	for (int i = next_led; i < NUM_PIXELS; i++) {
		leds.setPixelColor(i, s_color);
	}
	leds.show();
	last_draw_time = now;
}

/*
 * Wifi protocol code for the various modes
 */
void wifi_follow(int leader_id)
{
	Serial.println("In wifi_follow");
	WiFi.mode(WIFI_STA);
	String ssid = wifi_prefix + String(leader_id);
	Serial.print("ssid: ");
	Serial.print(ssid);
	Serial.println("  ");
	int rc = WiFi.begin(ssid.c_str());
	Serial.println("After WiFi.begin()");

	if (rc == WL_CONNECTED)
	{
		wifi_mode = MODE_FOLLOWER;
		Serial.print("Followed ");
		Serial.print(ssid);
		Serial.print(": ");
		Serial.println(WiFi.localIP());
	
	} else {
		wifi_mode = MODE_SCANNING;
		Serial.print("ERROR FOLLOWING: ");
		Serial.println(ssid);
	}
}


void wifi_create(int leader_id)
{
	WiFi.mode(WIFI_AP_STA);
	String ssid = wifi_prefix + String(leader_id);
	IPAddress ip(192,168,4,1);
	IPAddress gw(192,168,4,1);
	IPAddress subnet(255,255,255,0);
	WiFi.softAP(ssid.c_str());
	WiFi.config(ip, gw, subnet);
	wifi_mode = MODE_CANDIDATE;

	Serial.println("Candidate " + ssid + " " + WiFi.localIP());
}


void wifi_scanning()
{
	int min_leader = rescan_network();

	if (min_leader == 0)
		return;

	// if we found a new leader! join it
	if (min_leader > 0)
	{
		wifi_follow(min_leader);
		return;
	}

	// should we elect ourselves as a candidate?
	if (random(10) < wifi_scans)
	{
		wifi_scans = 0;
		wifi_create(wifi_my_id);
		// give myself a color BEFORE going into candidate mode
		uint32_t chosen_color = assignment_colors[random(COLORS_LENGTH)];
		add_to_used(chosen_color);
		my_color = chosen_color;

		return;
	}
}

void wifi_candidate()
{
	int min_leader = rescan_network();
	if (min_leader < 0)
		return;

	// there is a new leader out there, but don't follow if it
	// has an id higher than ours.
	if (min_leader != 0 && min_leader < wifi_my_id)
	{
		wifi_follow(min_leader);
		return;
	}

	// check to see if we have any followers
	int len = udp.parsePacket();
	if (len)
	{
		IPAddress ip = udp.remoteIP();
		Serial.print(ip);
		Serial.print(' ');
		Serial.print(len);
		udp.read(buf, sizeof(buf));
		for(int i = 0 ; i < len ; i++)
		{
			Serial.print(' ');
			Serial.print(buf[i], HEX);
		}

		Serial.println();

		// Parse this packet to see if it's a legit follower
		const message_t * message = (const message_t*) buf;
		// If we successfully took on a follower, transition to leader
		if (parse_follower_packet(message, ip))
		{
			Serial.println("going to leader mode");
			wifi_mode = MODE_LEADER;
		}
	}

	// Send a beacon to potential followers/leaders
	int now = millis();
	if (now - last_beacon > BEACON_INTERVAL)
	{
		message_t message = {
			BEACON_MAGIC,
			wifi_my_id,
			my_color
		};

		last_beacon = now;
		IPAddress bcast = WiFi.localIP();
		bcast[3] = 255;
		udp.beginPacket(bcast, UDP_PORT);
		udp.write((const uint8_t*) &message, sizeof(message));
		udp.endPacket();
	 	Serial.println("sent beacon");
	}
}

void wifi_follower()
{
	int now = millis();

	// did we get a packet from the leader?
	int len = udp.parsePacket();
	if (len)
	{
		IPAddress ip = udp.remoteIP();
		Serial.print(ip);
		Serial.print(' ');
		Serial.print(len);
		udp.read(buf, sizeof(buf));
		for(int i = 0 ; i < len ; i++)
		{
			Serial.print(' ');
			Serial.print(buf[i], HEX);
		}

		Serial.println();

		// parse the leader's packet
		const message_t * message = (const message_t*) buf;
		if (message->magic != BEACON_MAGIC && message->magic != ASSIGN_MAGIC)
		{
			Serial.println("unable to parse packet");
		} else if (message->magic == ASSIGN_MAGIC) {
			my_color = message->color;	
		} else {
			// assume it's a beacon
			Serial.print("leader: ");
			Serial.println(message->id);

			// Update follower state from beacon
			follower_state.leader_id = message->id;
			follower_state.leader_color = message->color;
			follower_state.leader_beacon_ms = millis();
		}
	}

	// have we lost our leader? if so, go into scanning mode
	if (now - follower_state.leader_beacon_ms > 10000)
	{
		wifi_mode = MODE_SCANNING;
		return;
	}
	
	// send our own beacon, if it's been a while
	if (now - follower_state.my_beacon_ms > BEACON_INTERVAL)
	{
		message_t message = {
			BEACON_MAGIC,
			wifi_my_id,
			my_color
		};

		follower_state.my_beacon_ms = now;
		IPAddress leader = WiFi.localIP();
		leader[3] = 1; // assume that the leader is also 192.168.x.1
		udp.beginPacket(leader, UDP_PORT);
		udp.write((const uint8_t *) &message, sizeof(message));
		udp.endPacket();
	}
}


void wifi_leader()
{
	// did we get a packet from a follower?
	int len = udp.parsePacket();
	if (len)
	{
		IPAddress ip = udp.remoteIP();
		Serial.print(ip);
		Serial.print(' ');
		Serial.print(len);
		udp.read(buf, sizeof(buf));
		for(int i = 0 ; i < len ; i++)
		{
			Serial.print(' ');
			Serial.print(buf[i], HEX);
		}

		Serial.println();

		// parse the follower's packet
		const message_t * message = (const message_t*) buf;
		parse_follower_packet(message, ip);
	}

	// If this is a new follower, send them a color assignment 

	// Send out our own beacon
	int now = millis();
	if (now - last_beacon > BEACON_INTERVAL)
	{
		message_t message = {
			BEACON_MAGIC,
			wifi_my_id,
			my_color
		};

		last_beacon = now;
		IPAddress bcast = WiFi.localIP();
		bcast[3] = 255; 
		udp.beginPacket(bcast, UDP_PORT);
		udp.write((const uint8_t *) &message, sizeof(message));
		udp.endPacket();
	}

}

// This is code was adapted from code from Adafruit
// Makes the rainbow equally distributed throughout
void rainbowCycle() {
  uint16_t i, j;
  int bright = 0;

  for(j=0; j<256*5; j++, bright = (bright + 1) % 4096) { // 5 cycles of all colors on wheel
    for(i=0; i< leds.numPixels(); i++) {
      uint32_t color = Wheel(((i * 256 / leds.numPixels()) + j) & 255);
      leds.setPixelColor(i, rgb_dim(color, bright / (4096 / 256)));
    }
    leds.show();
  }
}

void loop()
{
	switch(wifi_mode)
	{
		case MODE_SCANNING: {
			scanning_pattern();
			wifi_scanning();
			break;
		}
		case MODE_CANDIDATE: {
			candidate_pattern();
			wifi_candidate(); 
			break;
		}
		case MODE_FOLLOWER: {
			wifi_follower();
			follower_pattern();
			break;
		}
		case MODE_LEADER: {
			wifi_leader(); 
			leader_pattern();
			break;
		}
		default:
			wifi_mode = MODE_SCANNING;
	}


/*
	Serial.print(accel.read16(ADXL345_REG_DATAX0));
	Serial.print(' ');
	Serial.print(accel.read16(ADXL345_REG_DATAY0));
	Serial.print(' ');
	Serial.println(accel.read16(ADXL345_REG_DATAZ0));
	//Serial.println(accel.getDeviceID());
	sensors_event_t ev;  
	accel.getEvent(&ev);
	ax = (ax * smooth + ev.acceleration.x) / (smooth+1);
	ay = (ay * smooth + ev.acceleration.y) / (smooth+1);
	az = (az * smooth + ev.acceleration.z) / (smooth+1);
	
	Serial.print(rc);
	Serial.print(' ');
	Serial.print(ax);
	Serial.print(' ');
	Serial.print(ay);
	Serial.print(' ');
	Serial.print(az);
	Serial.println();
	Serial.print(accel.getX());
	Serial.print(' ');
	Serial.print(accel.getY());
	Serial.print(' ');
	Serial.print(accel.getZ());
	Serial.println();
	
	// circling status LED
	{
		boolean connected = WiFi.status() == WL_CONNECTED;

		int status_x, status_y;
		if (status_led < WIDTH)
		{
			status_x = status_led - 0;
			status_y = 0;
		} else
		if (status_led < WIDTH + HEIGHT)
		{
			status_x = WIDTH-1;
			status_y = status_led - WIDTH;
		} else
		if (status_led < 2 * WIDTH + HEIGHT)
		{
			status_x = 2 * WIDTH + HEIGHT - status_led - 1;
			status_y = HEIGHT-1;
		} else
		if (status_led < 2 * WIDTH + 2 * HEIGHT)
		{
			status_x = 0;
			status_y = 2 * WIDTH + 2 * HEIGHT - status_led - 1;
		}

		static unsigned f;
		if (f++ % 3 == 0)
			status_led = (status_led + 1) % (2*WIDTH + 2*HEIGHT);

		if (connected)
			fb[status_x][status_y][2] = 255;
		else
			fb[status_x][status_y][1] = 255;
	}


	for(int x = 0 ; x < WIDTH ; x++)
	{
		for(int y = 0 ; y < HEIGHT ; y++)
		{
			float *p = fb[x][y];

			// pulse red up and down
			p[0] += 128 * sin(t + x * 0.1 + y * 0.2);

			// fade and clamp it
			for(int i = 0 ; i < 3; i++)
			{
				float c = p[i] * 0.9;
				p[i] = c < 0 ? 0 : c > 255 ? 255 : c;
			}

			leds.setPixelColor(x+y*WIDTH, p[0], p[1], p[2]);
		}
	}

	t += 0.02;
	leds.show();
	delay(10);
*/
}

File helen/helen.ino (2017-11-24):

/** \file
 * HELEN board charlieplexing setup.
 *
 * This sketch uses Charlieplexing with four digital output pins
 * on the HELEN board to drive 6, 12 or 20 LEDs with PWM.
 * Note that with 20 LEDs you can't use USB.
 *
 * More info:
 *
 * https://trmm.net/HELEN
 * https://trmm.net/Charlieplex
 * https://trmm.net/PCB_Art
 * https://trmm.net/Catalan_PCB
 */

#include <avr/power.h>
#include <avr/sleep.h>

#if 0
#include <avr/wdt.h>

ISR(WDT_vect)
{
	wdt_disable();
}

/** Go into a deep sleep for 15ms */
void
deep_sleep()
{
	set_sleep_mode(SLEEP_MODE_IDLE);
	//set_sleep_mode(SLEEP_MODE_PWR_SAVE); // doesn't work

	// enables the sleep bit in the mcucr register
	// so sleep is possible. just a safety pin 
	sleep_enable();
  
	// turn off some of the things
	power_adc_disable();

	// enable the watch dog
	wdt_reset();
	wdt_enable(WDTO_15MS);
	sleep_mode();

	// we're back! disable sleep (the ISR turns off the watchdog)
	sleep_disable();

	//power_all_enable();
}
#endif



void setup()
{
	// switch the clock sel to 1/4, which should be 2 MHz.
#if 0
	CLKPR = 0x80;
	CLKPR = 0x02; // clk/4
#endif

	// disable any pin change interrupts that v-usb has enabled
	PCMSK = 0;

	off();
}

#define NUM_LEDS 20 // Maximum with 5 output pins
//#define NUM_LEDS 12 // Maximum with 4 output pins
//#define NUM_LEDS 6 // Maximum with 3 output pins

void off()
{
	DDRB = 0;
	PORTB = 0;
}

static inline void _on(const uint8_t vcc, const uint8_t gnd, const uint8_t state)
{
	if (state)
	{
		DDRB = (1 << vcc) | (1 << gnd);
		PORTB = (1 << vcc);
	} else {
		off();
	}
}

void led(const uint8_t n, const uint8_t state)
{
	switch(n)
	{
	case 0: _on(0, 1, state); break;
	case 1: _on(0, 2, state); break;
	case 2: _on(0, 5, state); break;
	case 3: _on(1, 0, state); break;
	case 4: _on(1, 2, state); break;
	case 5: _on(1, 5, state); break;
	case 6: _on(2, 0, state); break;
	case 7: _on(2, 1, state); break;
	case 8: _on(2, 5, state); break;
	case 9: _on(5, 0, state); break;
	case 10: _on(5, 1, state); break;
	case 11: _on(5, 2, state); break;
	case 12: _on(0, 4, state); break;
	case 13: _on(1, 4, state); break;
	case 14: _on(2, 4, state); break;
	case 15: _on(5, 4, state); break;
	case 16: _on(4, 0, state); break;
	case 17: _on(4, 1, state); break;
	case 18: _on(4, 2, state); break;
	case 19: _on(4, 5, state); break;
	default: off(); break;
	}
}

static uint8_t fb[NUM_LEDS];


void draw()
{
	for(uint8_t i = 0 ; i < 255-8 ; i += 8)
	{
		led(0, fb[0] > i);
		led(1, fb[1] > i);
		led(2, fb[2] > i);
		led(3, fb[3] > i);
		led(4, fb[4] > i);
		led(5, fb[5] > i);
#if NUM_LEDS > 6
		led(6, fb[6] > i);
		led(7, fb[7] > i);
		led(8, fb[8] > i);
		led(9, fb[9] > i);
		led(10, fb[10] > i);
		led(11, fb[11] > i);
#if NUM_LEDS > 12
		led(12, fb[12] > i);
		led(13, fb[13] > i);
		led(14, fb[14] > i);
		led(15, fb[15] > i);
		led(16, fb[16] > i);
		led(17, fb[17] > i);
		led(18, fb[18] > i);
		led(19, fb[19] > i);
#endif
#endif
	}
}


static inline void
decay(
	const uint8_t speed,
	const uint8_t min = 0
)
{
	for(uint8_t i = 0 ; i < NUM_LEDS ; i++)
	{
		if (fb[i] > min+speed)
			fb[i] -= speed;
	}
}

static inline void
decay_up(
	const uint8_t speed,
	const uint8_t min
)
{
	for(uint8_t i = 0 ; i < NUM_LEDS ; i++)
	{
		if (fb[i] < min)
			fb[i] += speed;
	}
}

void chase1(void)
{
	// "smooth" the x value across the leds
	// not quite as nice as the frame buffer decay approach
	for (int x = 0 ; x < 2048 ; x += 3)
	{
		for (int i = 0 ; i < NUM_LEDS ; i++)
		{
			int dx;
			if (x > 1024 && i < NUM_LEDS/2)
			{
				dx = x - (i+NUM_LEDS) * 2048/NUM_LEDS;
			} else {
				dx = x - i * 2048/NUM_LEDS;
			}
			if (dx < 0)
				dx = -dx;
			dx /= 2;
			if (dx > 255)
				dx = 255;
			fb[i] = 255 - dx;
		}
		draw();
	}
}


static void
chase2()
{
	uint8_t x1 = 0;
	uint8_t x2 = 6;
	uint8_t t1 = 0;
	uint8_t t2 = 0;

	while (random(10000) > 1)
	{
		if (fb[x1] < 200)
			fb[x1] += 16;
		if (fb[x2] < 200)
			fb[x2] += 6;

		if (t1++ > 37)
		{
			if (x1 == NUM_LEDS-1)
				x1 = 0;
			else
				x1++;
			t1 = 0;
		}

		if (t2++ > 17)
		{
			if (x2 == 0)
				x2 = NUM_LEDS-1;
			else
				x2--;
			t2 = 0;
		}

		draw();
		decay(1);
	}
}


void twinkle()
{
	while (random(10000) > 1)
	{
		if (random(200) < 2)
		{
			const uint8_t i = random(NUM_LEDS);
			if (i < NUM_LEDS)
				fb[i] = 200;
		}

		draw();
		decay(1);
	}
}

void soft_twinkle()
{
	const uint8_t min = 8;
	const uint8_t speed = 1;

	while (1) //random(10000) > 1)
	{
		const uint8_t chance = random(100);
		const uint8_t i = random(NUM_LEDS);
		if (chance < 1)
		{
			if (i < NUM_LEDS)
				fb[i] = 100;
		} else
		if (chance < 5)
		{
			if (i < NUM_LEDS)
				fb[i] = 1;
		}

		draw();
		decay(speed, min);
		if (random(5) == 0)
			decay_up(1, min);
		delay(2); // deep_sleep();
	}
}


static void
total_random()
{
	uint8_t max = 64;
	uint8_t dir[NUM_LEDS];
	uint8_t speed[NUM_LEDS];

	for(uint8_t i = 0 ; i < NUM_LEDS ; i++)
	{
		const uint8_t s = random(2)+1;

		fb[i] = random(max-s);
		dir[i] = 1;
		speed[i] = s;
	}

	while (random(10000) > 1)
	{
		uint16_t r = random(10000);
		for(uint8_t i = 0 ; i < NUM_LEDS ; i++)
		{
			const uint8_t b = fb[i];
			const uint8_t s = speed[i];
			r >>= 1;
			if (r & 1)
				continue;

			if (dir[i])
			{
				if (b+s > max)
				{
					dir[i] = 0;
				} else {
					fb[i] = b + s;
				}
			} else {
				if (b < s)
				{
					dir[i] = 1;
				} else {
					fb[i] = b - s;
				}
			}
		}
		draw();
		delay(15);
	}
			
}


static void
chase_smooth()
{
	const uint8_t speed = 1;
	int t = 0;

	while (++t < NUM_LEDS*64)
	{
		for(int i = 0 ; i < NUM_LEDS ; i++)
		{
			int x = i * 64;
			int dt = t - x;

			if (dt < -128 || dt > 128)
				fb[i] = 0;
			else
			if (dt < 0)
				fb[i] = 64+dt/2;
			else
				fb[i] = 64-dt/2;
		}

		draw();
		//delay(10);
	}
}

// simple binary on/off
void chase0()
{
	const int delay_ms = 200;
	led(0, 1); delay(delay_ms);
	led(1, 1); delay(delay_ms);
	led(2, 1); delay(delay_ms);
	led(3, 1); delay(delay_ms);
	led(4, 1); delay(delay_ms);
	led(5, 1); delay(delay_ms);
#if NUM_LEDS > 6
	led(6, 1); delay(delay_ms);
	led(7, 1); delay(delay_ms);
	led(8, 1); delay(delay_ms);
	led(9, 1); delay(delay_ms);
	led(10, 1); delay(delay_ms);
	led(11, 1); delay(delay_ms);
#if NUM_LEDS > 12
	led(12, 1); delay(delay_ms);
	led(13, 1); delay(delay_ms);
	led(14, 1); delay(delay_ms);
	led(15, 1); delay(delay_ms);
	led(16, 1); delay(delay_ms);
	led(17, 1); delay(delay_ms);
	led(18, 1); delay(delay_ms);
	led(19, 1); delay(delay_ms);
#endif
#endif
	off();
	led(0, 1); delay(500);
	off();
	delay(500);
}

void loop()
{
	while(1)
		chase2();

if(0)
{
	chase1();
	chase2();
	twinkle();
	chase_smooth();
	total_random();
}
	soft_twinkle();
}

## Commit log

2014-07-16 import of pcb and micro-usb
    [pendant.brd, pendant.sch]
2014-07-17 added square cutout magnet, worked on board outline
    [pendant.brd, pendant.sch]
2014-07-17 switch to 8th-inch magnet
    [pendant.brd, pendant.sch]
2014-07-17 fix usb wiring bug; fully routed
    [pendant.brd, pendant.sch]
2014-07-29 port code to arduino and common cathode for new board
2014-08-06 random fixes for common cathode
    [cycle.ino]
2015-01-19 circular pendant with 12 LEDs
    [helen-circle.brd, helen-circle.sch]
2015-02-08 working loader for helen board
2015-02-08 laser cut face for helen circle board
2015-02-10 deep sleep; save the battery
2016-03-25 adding some new led patterns for scanning and following mode
2016-03-26 rearrange to work with arduino 1.6.7
2016-03-28 8x8 addressable matrix with feather wing board and accelerometer on the back
    [Pendant64-matrix.brd, Pendant64-matrix.sch]
2016-03-28 added a second AAA battery, relocated wifi to center of board
    [Pendant64-matrix.brd, Pendant64-matrix.sch]
2016-04-09 does not work -- but about to make it worse. adding leader code.
    [wifi.ino]
2016-04-10 Fixing broadcast of leader packets so they are received by followers.
    [wifi.ino]
2016-04-12 shortening rescan interval, follower now pulses self color when it sends a packet, leader relinquishes leds for lost followers
    [color.ino, wifi.ino]
2016-04-14 color assignmest from leader to follower are now working, but wifi protocol is no longer stable so leaders quickly revert to scanning after attaining a follower.
    [wifi.ino]
2016-04-14 fixing one obvious bug where it was claiming the used_colors array was full if one slot was empty, still not acquiring followers.
    [wifi.ino]
2016-04-15 removing infinite loop, but followers are still getting errors when trying to join. Next step: moving some of the color assignment code out into a function to make debugging easier.
    [wifi.ino]
2016-04-15 working now! One magical line of code stabilizes connections: WiFi.persistant(false), and followers can connect to leaders now. Still not keeping track of used colors, just picking randomly from the 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
2016-04-17 adding a delay when drawing LEDs to try to help leaders hear followers who are trying to connect. seems to help a little
2017-05-03 parts placed and routed
    [helen-art.brd, helen-art.sch]
2017-05-03 fix D+/D- swap and remove LED labels
    [helen-art.brd, helen-art.sch]
2017-05-03 text on the back, ready to order
    [helen-art.brd]
2017-05-12 values for resistors
    [helen-art.brd, helen-art.sch]
2017-05-16 board without any artwork
    [helen-art.brd]
2017-05-19 no more clearance issues
    [helen-art.brd]
2017-05-19 add image back in
    [helen-art.brd]
2017-05-19 updates for teensy and arduino 1.6.11
2017-11-24 updates for 20 output boards
2017-12-18 flexible Catalan hexecontahedron PCB
    [hexecontahedron.brd, hexecontahedron.sch]

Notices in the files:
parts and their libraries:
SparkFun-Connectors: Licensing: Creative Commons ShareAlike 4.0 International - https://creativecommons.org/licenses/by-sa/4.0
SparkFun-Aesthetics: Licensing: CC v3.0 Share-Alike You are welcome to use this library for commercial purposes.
